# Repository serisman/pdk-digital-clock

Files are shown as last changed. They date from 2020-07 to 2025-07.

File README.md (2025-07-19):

# pdk-digital-clock
A 4-digit 7-segment digital clock, based on the inexpensive 8-bit Padauk microcontrollers

This project uses the [SLR0394DRC5BD](https://lcsc.com/product-detail/Led-Segment-Display_SUNLIGHT-SLR0394DRA5BD_C225902.html) 4-digit 7-segment common cathode 'time' display,
which sits over the top of a 74HC595 and (2) 4x resistor packs.
The 74HC595 is used to enable each of the four 7-segment digits, one at a time, using two output pins per digit for extra current sink capabilities.
The segments themselves are driven directly by the Port B outputs of the Padauk microcontroller.
Each of the four 7-segment digits is enabled and updated, one at a time, several 10's of times a second.

### Default Firmware (Push Button)
- Link: [Firmware](firmware/)

A single push button is used to set the time, with the following 'user interface':
- A short press will temporarily show the current 'seconds'.
- A medium-press will switch to time config mode.  While in config mode:
  - A short press will increment the currently selected time value, with rollover.
  - A medium-press will switch to the next time value, or exit config mode if on the last time value.
  - A long-press will exit config mode. 

### Alternate Firmware (Serial)
- Link: [Firmware-Serial](firmware-serial/)

This alternate firmware allows the time to be set by a serial command instead of requiring button presses.
This makes it easier to keep time updated and synced after it naturally drifts due to crystal accuracy and temperature fluctuations.

To set/update time, connect a Serial UART's TX pin (TTL level) to pin PA5 (PIN_RX):
- Send the following 5 bytes @9600 baud (1 start bit, 8 data bits, 1 stop bit, no parity):
    - `start byte`: 0x00
    - `hours byte`: using bcd notation, bit[7] is am_pm indicator, bits[5:4] is hours_10, bits[3:0] is hours_01
    - `minutes byte`: using bcd notation, bits[6:4] is minutes_10, bits[3:0] is minutes_01
    - `seconds byte`: using bcd notation, bits[6:4] is seconds_10, bits[3:0] is seconds_01
    - `checksum byte`: the sum of all preceding data bytes.

### Power Consumption

This digital clock is powered via micro USB cable, although it should work at much lower voltages as well.
It isn't really suitable for long-term battery operation, as the LED based 7-segment display consumes enough energy that the battery wouldn't last very long.

#### Power consumption (displaying 12:00):
- @ 5.0V = ~19mA
- @ 4.5V = ~16mA
- @ 4.0V = ~13mA
- @ 3.5V = ~10mA
- @ 3.0V = ~7mA
- @ 2.5V = ~4mA
- @ 2.0V = ~1mA

### PCB
- Design Files: [KiCad](pcb-s16/)
- Shared: [OSHPARK](https://oshpark.com/shared_projects/jvGgF1gC)

### Schematic
(for 16-pin PFS154, PFS173, PMS152, or PMS154C)
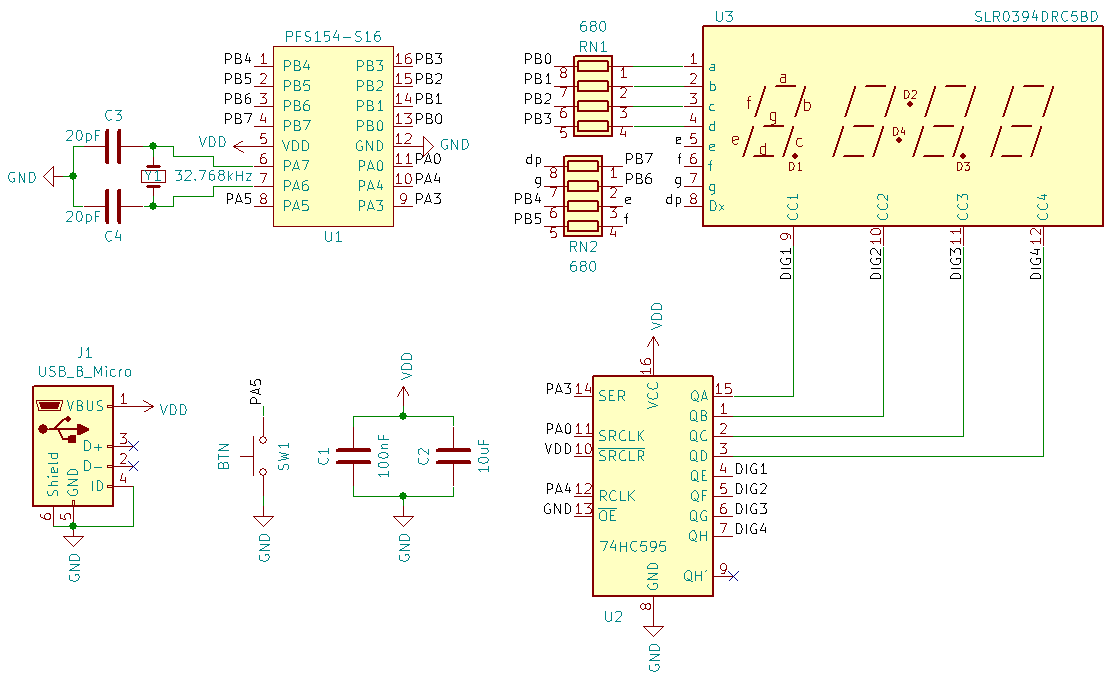
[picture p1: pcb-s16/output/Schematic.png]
Schematic
> 

### Compatibility
This project is currently intended to be run (without modifications) on the PFS154, PFS173, PMS152, and PMS154C Padauk microcontrollers,
but it should be able to be modified to run on other 16-pin Padauk microcontrollers that are supported by SDCC and the Easy PDK Programmer.

### Bill of Materials
| Ref | Part # | Description | Footprint | Purchase Link | Price | Minimum Purchase |
| --- | --- | --- | --- | --- | --- | --- |
| PCB | - | - | - | [OSHPARK](https://oshpark.com/shared_projects/jvGgF1gC) | $1.033 each | $3.10 for 3 |
| U3 | SLR0394DRA5BD | 4-digit time-mode 7-segment display | - | [LCSC C225902](https://lcsc.com/product-detail/Led-Segment-Display_SUNLIGHT-SLR0394DRA5BD_C225902.html) | $0.501 each | $0.501 for 1|  
| U1 | PMS152-S16 | 8-bit Padauk microcontroller | SOP-16 | [LCSC C317590](https://lcsc.com/product-detail/Others_PADAUK-Tech-PMS152-S16_C317590.html) | $0.077 each | $0.39 for 5 |
| U2 | 74HC595D | Serial shift register | SOP-16 | [LCSC C93838](https://lcsc.com/product-detail/LED-Drivers_Shenzhen-Sunmoon-Micro-SM74HC595D_C93838.html) | $0.046 each | $0.46 for 10 |
| Y1 | - | 32.767KHz radial cylinder crystal | 2x6mm | [LCSC C2236](https://lcsc.com/product-detail/Radial-Cylinder-Crystals_Yangxing-Tech-X206032768KGB2SC_C2236.html) | $0.045 each | $0.45 for 10 |
| J1 | - | Micro USB connector | - | [LCSC C393940](https://lcsc.com/product-detail/USB-Connectors_SHOU-HAN-MICRO5-9mmusb_C393940.html) | $0.026 each | $0.52 for 20 | 
| SW1 | TS24CA | SPST side-actuated button tactile switch | - | [LCSC C393942](https://lcsc.com/product-detail/Tactile-Switches_SHOU-HAN-TS24CA_C393942.html) | $0.025 each | $0.50 for 20 |
| C2 | - | 10uF capacitor | 0805 | [LCSC C92786](https://lcsc.com/product-detail/Multilayer-Ceramic-Capacitors-MLCC-SMD-SMT_Taiyo-Yuden_JMK212BJ106KD-T_Taiyo-Yuden-JMK212BJ106KD-T_C92786.html) | $0.015 each | $0.73 for 50 |
| C3,C4 | - | 20pF capacitor | 0805 | [LCSC C309037](https://lcsc.com/product-detail/Multilayer-Ceramic-Capacitors-MLCC-SMD-SMT_CCTC-TCC0805C0G200J500BT_C309037.html) | $0.007 each | $0.36 for 50 |
| RN1,RN2 | - | 4x 680 ohm resistor network | 0603_x4 | [LCSC C102679](https://lcsc.com/product-detail/Resistor-Networks-Arrays_RALEC-RTA03-4D681JTP_C102679.html) | $0.007 each | $0.35 for 50 |
| C1 | - | 100nF capacitor | 0805 | [LCSC C235732](https://lcsc.com/product-detail/Multilayer-Ceramic-Capacitors-MLCC-SMD-SMT_PSA-Prosperity-Dielectrics-FN21X104K500PXG_C235732.html) | $0.006 each | $0.30 for 50 |

Total: ~$1.80 each (+/- depending on quantity)

### Images
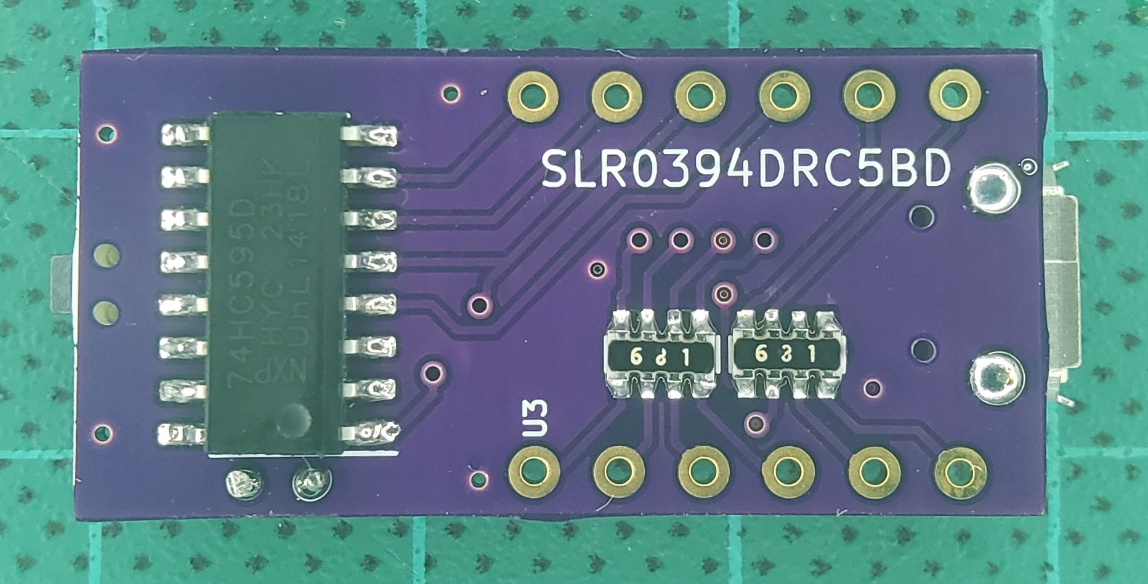
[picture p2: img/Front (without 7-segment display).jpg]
Front (without 7-segment display)

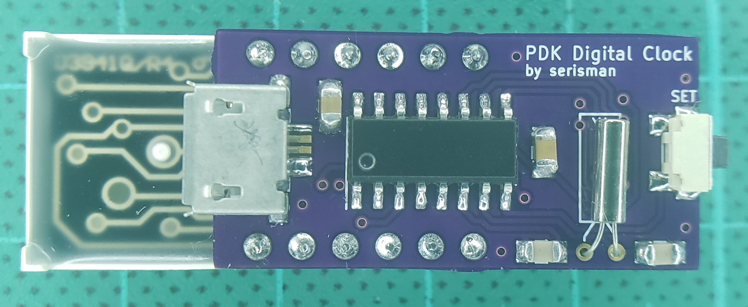
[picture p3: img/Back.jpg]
Back

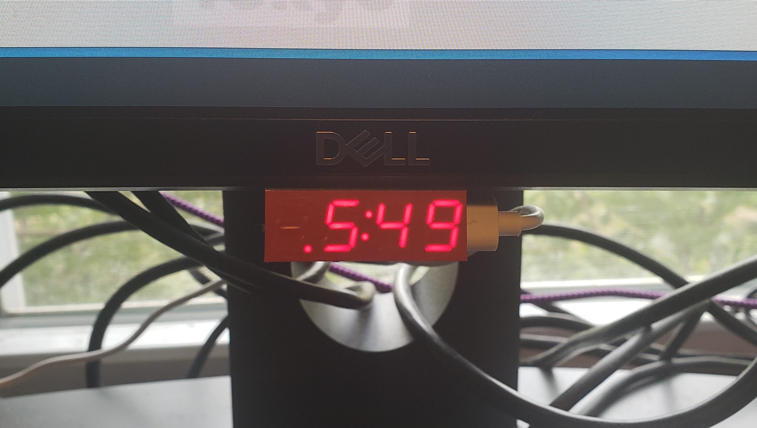
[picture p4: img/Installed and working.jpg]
Installed and working!


### Copyright and License:
- Copyright (C) 2020 - serisman (github@serisman.com)
- License: [GPL v3 (or later)](LICENSE)

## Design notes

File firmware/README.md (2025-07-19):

# firmware ([pdk-digital-clock](https://github.com/serisman/pdk-digital-clock/))

A single push button is used to set the time, with the following 'user interface':
- A short press will temporarily show the current 'seconds'.
- A medium-press will switch to time config mode.  While in config mode:
    - A short press will increment the currently selected time value, with rollover.
    - A medium-press will switch to the next time value, or exit config mode if on the last time value.
    - A long-press will exit config mode.

### Toolchain:
- The open-source [Small Device C Compiler (SDCC)](http://sdcc.sourceforge.net/)
  - Requires version 4.4.0+
- The open-source [Easy PDK Programmer](https://github.com/free-pdk/easy-pdk-programmer-software)
  - Requires version 1.3 or newer
- The open-source [pdk-includes](https://github.com/free-pdk/pdk-includes) repository
  - Integrated via local copy into the pdk/ directory
- The open-source [easy-pdk-includes](https://github.com/free-pdk/easy-pdk-includes) repository
  - Integrated via local copy into the easy-pdk/ directory
- Also requires 'make' and other common build tools

### Build Commands:
```
make clean
make build
make size (also calls build)
make program (also calls size which calls build)
make run
```
> Note: These commands can be chained as well.  i.e. `make clean program run`

### Customization:
Edit the variables at the top of the Makefile to:
- **DEVICE**: Use a different Padauk MCU (defaults to PFS154)
- **F_CPU**: Use a different frequency for the system clock (defaults to 524.288 kHz, i.e. IHRC/32)
  > Note: Valid choices are: 524288 to use the IHRC, or 65536 to use the ILRC.  These values make it easier for timekeeping (although true accuracy only comes from using an external crystal).
- **TARGET_VDD_MV**: Use a different voltage while calibrating the internal oscillator (IHRC or ILRC) (defaults to 4000mV)
- **TARGET_VDD**: Use a different voltage while the IC is operating (defaults to 4.0V)
- **DEBUG**: If set to 1, the 16-bit timer will use the less accurate internal oscillator instead of requiring an external crystal (defaults to 0)

> Note: All of these variables can be changed on the commandline as well.  i.e. `make DEVICE=PFS173 clean program run` 

### Compatibility
This project is currently intended to be run (without modifications) on the PFS154, PFS173, PMS152, and PMS154C Padauk microcontrollers,
but it should be able to be modified to run on other 16-pin Padauk microcontrollers that are supported by SDCC and the Easy PDK Programmer.
Less common devices may require additional device specific include files (pdk/device/*.h) to be supplied.

### Build Stats
- Code Size: ~463 words
- RAM usage: 22 bytes + stack

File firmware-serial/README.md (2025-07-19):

# firmware-serial ([pdk-digital-clock](https://github.com/serisman/pdk-digital-clock/))

This alternate firmware allows the time to be set by a serial command instead of requiring button presses.
This makes it easier to keep time updated and synced after it naturally drifts due to crystal accuracy and temperature fluctuations.

To set/update time, connect a Serial UART's TX pin (TTL level) to pin PA5 (PIN_RX):
- Send the following 5 bytes @9600 baud (1 start bit, 8 data bits, 1 stop bit, no parity):
  - `start byte`: 0x00
  - `hours byte`: using bcd notation, bit[7] is am_pm indicator, bits[5:4] is hours_10, bits[3:0] is hours_01
  - `minutes byte`: using bcd notation, bits[6:4] is minutes_10, bits[3:0] is minutes_01
  - `seconds byte`: using bcd notation, bits[6:4] is seconds_10, bits[3:0] is seconds_01
  - `checksum byte`: the sum of all preceding data bytes.

### Toolchain:
- The open-source [Small Device C Compiler (SDCC)](http://sdcc.sourceforge.net/)
  - Requires version 4.4.0+
- The open-source [Easy PDK Programmer](https://github.com/free-pdk/easy-pdk-programmer-software)
  - Requires version 1.3 or newer
- The open-source [pdk-includes](https://github.com/free-pdk/pdk-includes) repository
  - Integrated via local copy into the pdk/ directory
- The open-source [easy-pdk-includes](https://github.com/free-pdk/easy-pdk-includes) repository
  - Integrated via local copy into the easy-pdk/ directory
- Also requires 'make' and other common build tools

### Build Commands:
```
make clean
make build
make size (also calls build)
make program (also calls size which calls build)
make run
```
> Note: These commands can be chained as well.  i.e. `make clean program run`

### Customization:
Edit the variables at the top of the Makefile to:
- **DEVICE**: Use a different Padauk MCU (defaults to PFS154)
- **F_CPU**: Use a different frequency for the system clock (defaults to 524.288 kHz, i.e. IHRC/32)
  > Note: Only valid choice is: 524288 to use the IHRC.  This value make it easier for timekeeping (although true accuracy only comes from using an external crystal).
          Changing this would also require changes to the UART receive code which has very precise timing requirements.
- **TARGET_VDD_MV**: Use a different voltage while calibrating the internal oscillator (IHRC or ILRC) (defaults to 3300mV)
- **TARGET_VDD**: Use a different voltage while the IC is operating (defaults to 3.3V)
- **DEBUG**: If set to 1, the 16-bit timer will use the less accurate internal oscillator instead of requiring an external crystal (defaults to 0)

> Note: All of these variables can be changed on the commandline as well.  i.e. `make DEVICE=PFS173 clean program run` 

### Compatibility
This project is currently intended to be run (without modifications) on the PFS154, PFS173, PMS152, and PMS154C Padauk microcontrollers,
but it should be able to be modified to run on other 16-pin Padauk microcontrollers that are supported by SDCC and the Easy PDK Programmer.
Less common devices may require additional device specific include files (pdk/device/*.h) to be supplied.

### Build Stats
- Code Size: ~365 words
- RAM usage: 28 bytes + stack

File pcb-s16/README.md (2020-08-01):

# pcb-s16 ([pdk-digital-clock](https://github.com/serisman/pdk-digital-clock/))

### Schematic
(for 16-pin PFS154, PFS173, PMS152, or PMS154C)
> Schematic

### PCB

This PCB design was created with KiCad, and has been [shared on OSHPARK](https://oshpark.com/shared_projects/jvGgF1gC).
There are also gerber files available in the [output/gerber/](output/gerber/) directory.

This uses the [SLR0394DRC5BD](https://lcsc.com/product-detail/Led-Segment-Display_SUNLIGHT-SLR0394DRA5BD_C225902.html) 4-digit 7-segment common cathode 'time' display,
which sits over the top of the 74HC595 and the (2) 4x resistor packs.
The 74HC595 is used to drive the (4) 7-segment digits, (2) outputs per digit for extra current sink capabilities.
The segments themselves are driven directly by the Port B outputs of the Padauk microcontroller.

A single push button is used to set the time, with the following 'user interface':
- A short press will temporarily show the current 'seconds'.
- A medium-press will switch to time config mode.  While in config mode:
  - A short press will increment the currently selected time value, with rollover.
  - A medium-press will switch to the next time value, or exit config mode if on the last time value.
  - A long-press will exit config mode. 

This digital clock is powered via micro USB cable, although it should work at much lower voltages as well.
It isn't really suitable for long-term battery operation, as the LED based 7-segment display consumes enough energy that it wouldn't last very long.

### Bill of Materials
| Ref | Part # | Description | Footprint | Purchase Link | Price | Minimum Purchase |
| --- | --- | --- | --- | --- | --- | --- |
| PCB | - | - | - | [OSHPARK](https://oshpark.com/shared_projects/jvGgF1gC) | $1.033 each | $3.10 for 3 |
| U3 | SLR0394DRA5BD | 4-digit time-mode 7-segment display | - | [LCSC C225902](https://lcsc.com/product-detail/Led-Segment-Display_SUNLIGHT-SLR0394DRA5BD_C225902.html) | $0.501 each | $0.501 for 1|  
| U1 | PMS152-S16 | 8-bit Padauk microcontroller | SOP-16 | [LCSC C317590](https://lcsc.com/product-detail/Others_PADAUK-Tech-PMS152-S16_C317590.html) | $0.077 each | $0.39 for 5 |
| U2 | 74HC595D | Serial shift register | SOP-16 | [LCSC C93838](https://lcsc.com/product-detail/LED-Drivers_Shenzhen-Sunmoon-Micro-SM74HC595D_C93838.html) | $0.046 each | $0.46 for 10 |
| Y1 | - | 32.767KHz radial cylinder crystal | 2x6mm | [LCSC C2236](https://lcsc.com/product-detail/Radial-Cylinder-Crystals_Yangxing-Tech-X206032768KGB2SC_C2236.html) | $0.045 each | $0.45 for 10 |
| J1 | - | Micro USB connector | - | [LCSC C393940](https://lcsc.com/product-detail/USB-Connectors_SHOU-HAN-MICRO5-9mmusb_C393940.html) | $0.026 each | $0.52 for 20 | 
| SW1 | TS24CA | SPST side-actuated button tactile switch | - | [LCSC C393942](https://lcsc.com/product-detail/Tactile-Switches_SHOU-HAN-TS24CA_C393942.html) | $0.025 each | $0.50 for 20 |
| C2 | - | 10uF capacitor | 0805 | [LCSC C92786](https://lcsc.com/product-detail/Multilayer-Ceramic-Capacitors-MLCC-SMD-SMT_Taiyo-Yuden_JMK212BJ106KD-T_Taiyo-Yuden-JMK212BJ106KD-T_C92786.html) | $0.015 each | $0.73 for 50 |
| C3,C4 | - | 20pF capacitor | 0805 | [LCSC C309037](https://lcsc.com/product-detail/Multilayer-Ceramic-Capacitors-MLCC-SMD-SMT_CCTC-TCC0805C0G200J500BT_C309037.html) | $0.007 each | $0.36 for 50 |
| RN1,RN2 | - | 4x 680 ohm resistor network | 0603_x4 | [LCSC C102679](https://lcsc.com/product-detail/Resistor-Networks-Arrays_RALEC-RTA03-4D681JTP_C102679.html) | $0.007 each | $0.35 for 50 |
| C1 | - | 100nF capacitor | 0805 | [LCSC C235732](https://lcsc.com/product-detail/Multilayer-Ceramic-Capacitors-MLCC-SMD-SMT_PSA-Prosperity-Dielectrics-FN21X104K500PXG_C235732.html) | $0.006 each | $0.30 for 50 |

Total: ~$1.80 each (+/- depending on quantity)

### PCB Renders

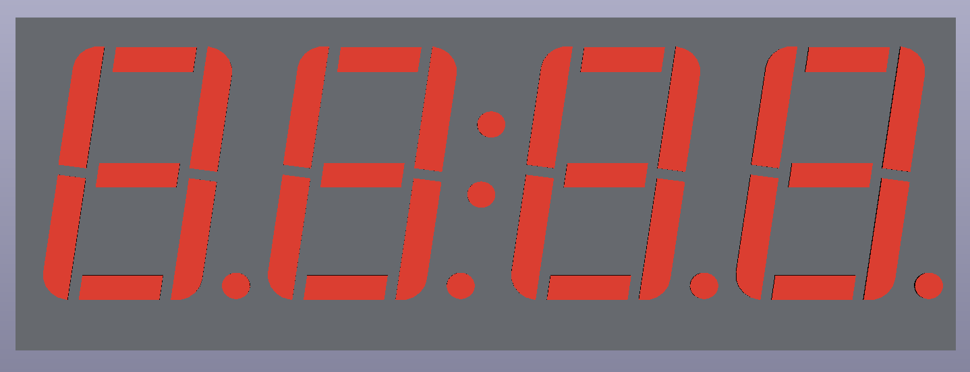
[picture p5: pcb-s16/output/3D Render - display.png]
3D Render - display

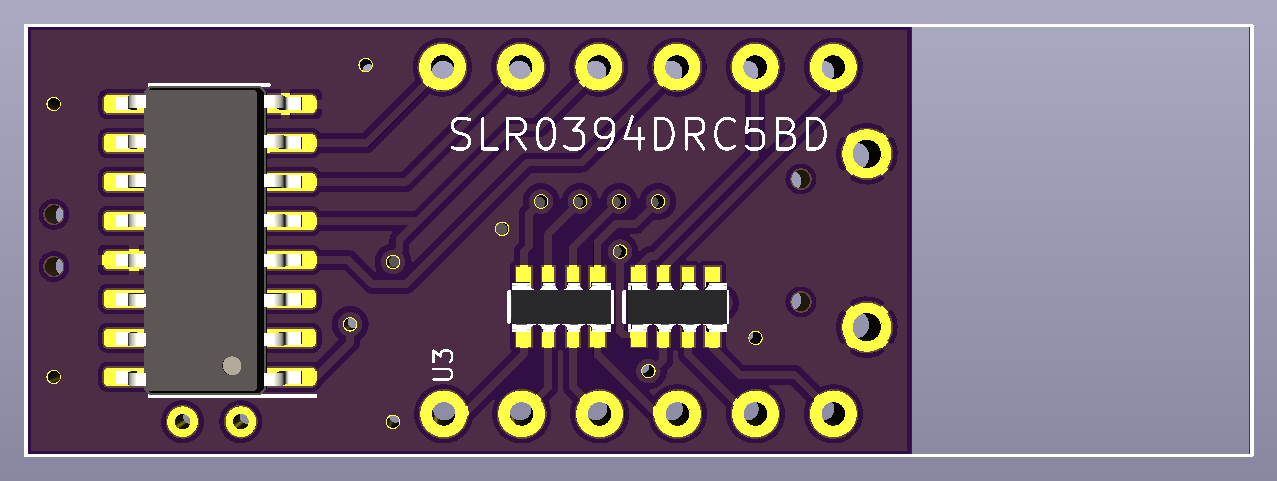
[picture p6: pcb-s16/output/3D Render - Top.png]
3D Render - Top

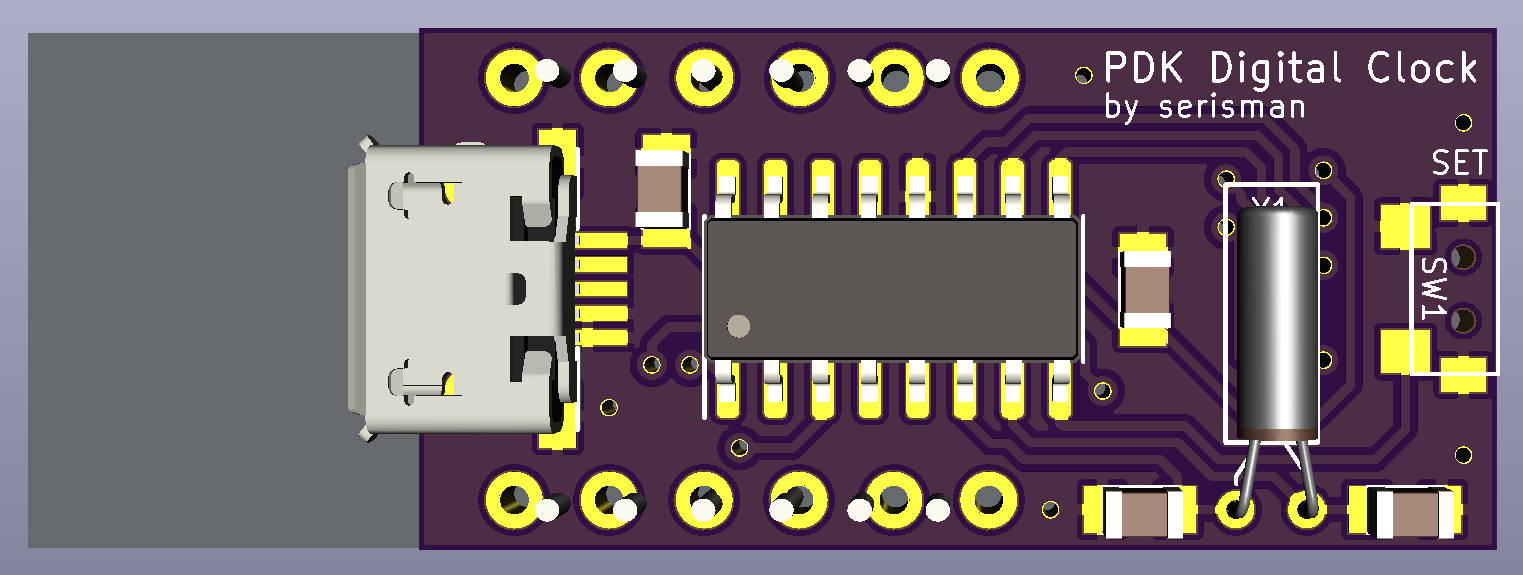
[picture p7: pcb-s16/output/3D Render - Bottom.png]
3D Render - Bottom

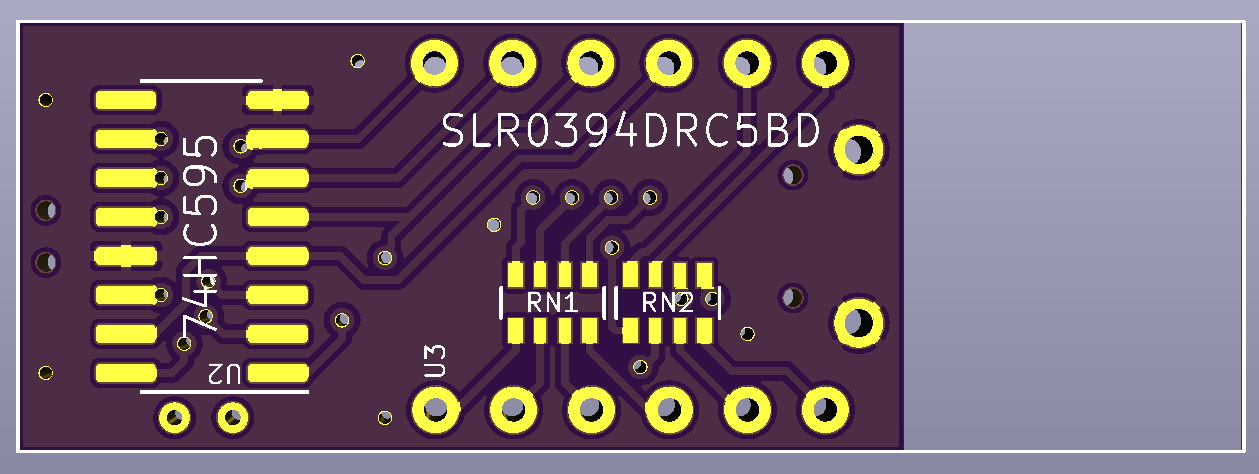
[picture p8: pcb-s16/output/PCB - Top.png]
PCB Top

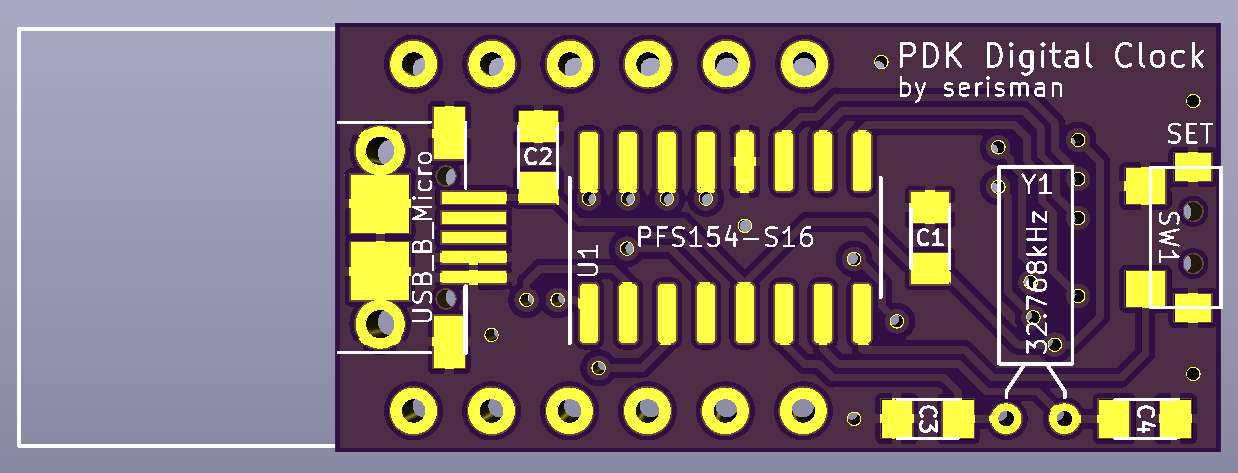
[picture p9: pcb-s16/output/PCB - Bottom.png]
PCB Bottom


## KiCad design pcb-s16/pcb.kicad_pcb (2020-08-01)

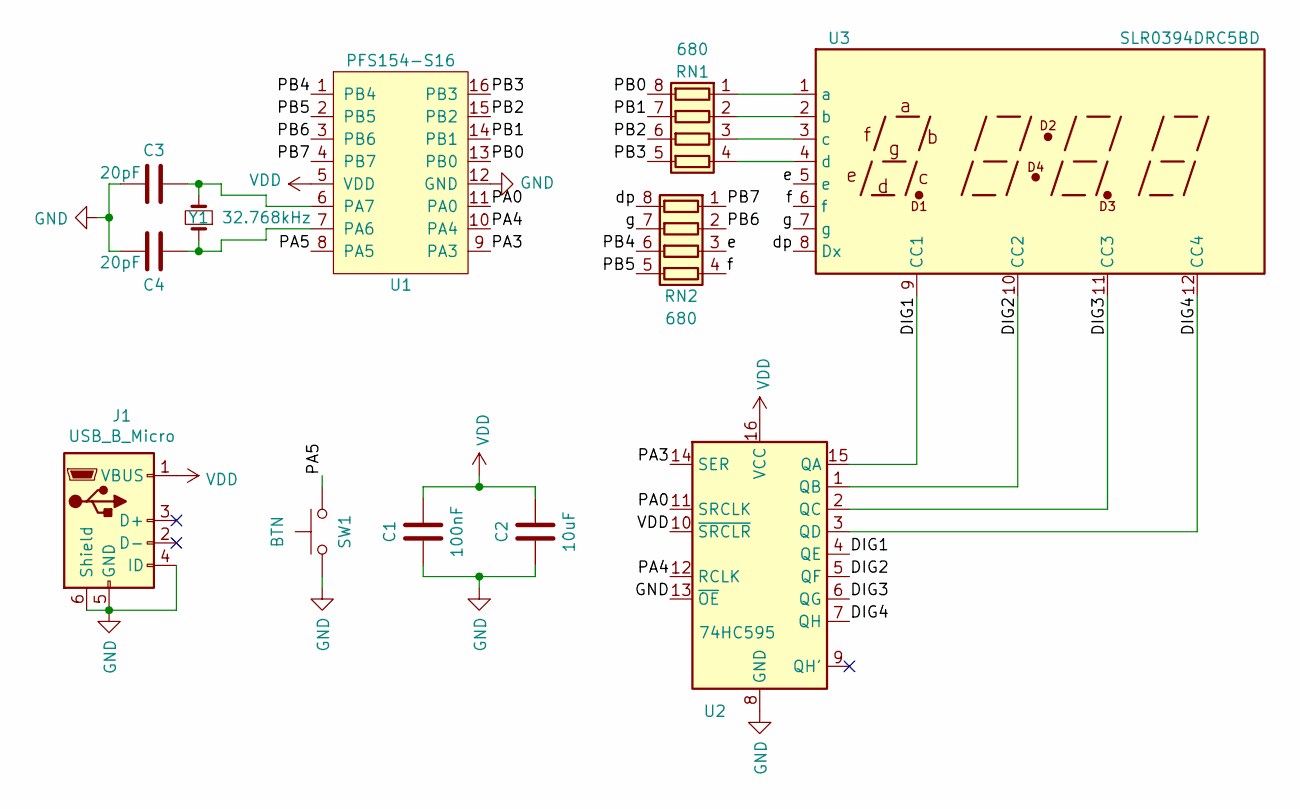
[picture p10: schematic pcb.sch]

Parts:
C1: 100nF; C_0805
C2: 10uF; C_0805
C3, C4: 20pF; C_0805
J1: USB_B_Micro; USB_Micro_B_Male
RN1, RN2: 680; R_Array_Convex_4x0603
SW1: BTN; SMD-SW_Push_3.5x4.55_Side
U1: PFS154-S16; SOIC-16_3.9x9.9mm_P1.27mm
U2: 74HC595; SOIC-16_3.9x9.9mm_P1.27mm
U3: SLR0394DRC5BD; SLR039DRC5BD
Y1: 32.768kHz; Crystal_C26-LF_D2.1mm_L6.5mm_Horizontal

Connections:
/DIG1: U2.4 (QE), U2.15 (QA), U3.9 (CC1)
/DIG2: U2.1 (QB), U2.5 (QF), U3.10 (CC2)
/DIG3: U2.2 (QC), U2.6 (QG), U3.11 (CC3)
/DIG4: U2.3 (QD), U2.7 (QH), U3.12 (CC4)
/PA0: U1.11 (PA0), U2.11 (SRCLK)
/PA3: U1.9 (PA3), U2.14 (SER)
/PA4: U1.10 (PA4), U2.12 (RCLK)
/PA5: SW1.2, U1.8 (PA5)
/PB0: RN1.8 (R1.2), U1.13 (PB0)
/PB1: RN1.7 (R2.2), U1.14 (PB1)
/PB2: RN1.6 (R3.2), U1.15 (PB2)
/PB3: RN1.5 (R4.2), U1.16 (PB3)
/PB4: RN2.6 (R3.2), U1.1 (PB4)
/PB5: RN2.5 (R4.2), U1.2 (PB5)
/PB6: RN2.2 (R2.1), U1.3 (PB6)
/PB7: RN2.1 (R1.1), U1.4 (PB7)
/dp: RN2.8 (R1.2), U3.8 (Dx)
/e: RN2.3 (R3.1), U3.5 (e)
/f: RN2.4 (R4.1), U3.6 (f)
/g: RN2.7 (R2.2), U3.7 (g)
GND: C1.2, C2.2, C3.1, C4.1, J1.4 (ID), J1.5 (GND), J1.6 (Shield), SW1.1, SW1.SH, U1.12 (GND), U2.8 (GND), U2.13 (~OE)
unnamed: C3.2, U1.6 (PA7), Y1.2
unnamed: C4.2, U1.7 (PA6), Y1.1
unnamed: RN1.1 (R1.1), U3.1 (a)
unnamed: RN1.2 (R2.1), U3.2 (b)
unnamed: RN1.3 (R3.1), U3.3 (c)
unnamed: RN1.4 (R4.1), U3.4 (d)
VDD: C1.1, C2.1, J1.1 (VBUS), U1.5 (VDD), U2.10 (~SRCLR), U2.16 (VCC)

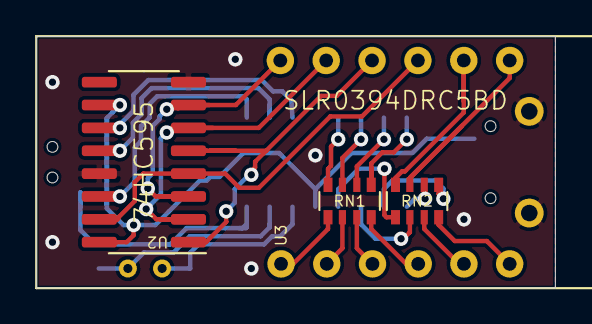
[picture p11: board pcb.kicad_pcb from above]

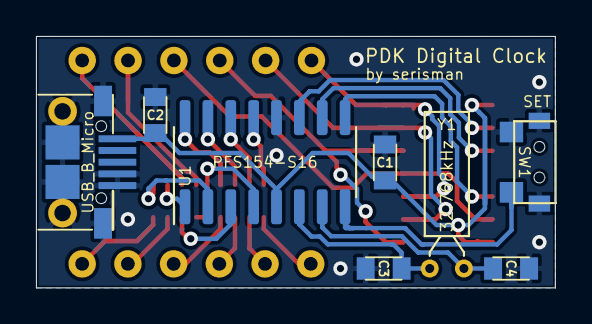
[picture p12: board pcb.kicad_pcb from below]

Board: 2 copper layers, 28.8 x 14.0 mm, 12 parts (8 on the bottom side), 28 nets.

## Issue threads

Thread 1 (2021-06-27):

Issue with pfs173 reset pin as a PRSTB function

Vanbatai123, 2021-06-27:
Hi sir!
I have an issue that how to configure pin A5 as a PRSTB reset pin, i have read datasheet and try it like this but did not work.

uint8_t _sdcc_external_startup(void)
{
	PAC &= ~(1<<5);
	CLKMD |= (1<<0);
	EASY_PDK_INIT_SYSCLOCK_8MHZ();		  //use 8MHz sysclock
	EASY_PDK_CALIBRATE_IHRC(F_CPU, 5000); //tune SYSCLK to 8MHz @ 4.000V
	return 0;							  //perform normal initialization
}
thank in advance.

Closed 2022-07-05.

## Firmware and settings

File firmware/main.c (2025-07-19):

/*
  main.c: Main program code for the PDK digital clock project.

  Copyright (C) 2020  serisman  <github@serisman.com>

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
  You should have received a copy of the GNU General Public License
  along with this program.  If not, see <http://www.gnu.org/licenses/>.
*/

#include <pdk/device.h>
#include <easy-pdk/calibrate.h>
#include "util.h"

#define PORT_SEGMENTS   PB
#define PIN_SR_DATA     PA,3
#define PIN_SR_CLOCK    PA,0
#define PIN_SR_LATCH    PA,4

#define PIN_BTN         PA,5

volatile uint8_t quarter_seconds;

// Initialize clock to 12:00:00 AM
uint8_t hours_10=1, hours_01=2, minutes_10, minutes_01, seconds_10, seconds_01, am_pm;

// Initialize display to --:--
uint8_t digit1=0b01000000, digit2=0b01000000, digit3=0b01000000, digit4=0b01000000;
uint8_t current_digit_mask = 0b10001000;

uint8_t _tmp, prev_quarter_seconds, btn_ctr, display_mode, config_mode, config_ctr;

// void display_next_digit()
//
//  Rotates to and outputs a single digit 'register' for a 4-digit 7-segment display.
//  NOTE: This should be called multiple 100's of times a second to light up all the digits for 'persistence of vision'.
//    This method has been written in assembly to make it as small and fast as possible.
//  This uses a 74HC595 as a digit 'driver' which provides two benefits:
//   1. Enables 4 (or more) outputs (digits) from 3 IO pins.
//   2. Enables a higher current sink for each digit than IO pins would otherwise allow.
//  We double up the 74HC595 output pins (i.e. 2 per digit) for extra current sink capability.
//
//  Assumes (#define'd above):
//   Segments[a-g,dp] are mapped to PB[0-7]
//   74HC595 (14) DS - DATA is on PA3
//   74HC595 (11) SH_CP - CLOCK is on PA0
//   74HC595 (12) ST_CP - LATCH is on PA4
void display_next_digit(void) {
__asm
	;// Rotate to next digit
  set0.io  f, c
  t0sn  _current_digit_mask, #7
    set1.io  f, c
  slc   _current_digit_mask

	;// Shift out /EN for all digits to 74HC595
	mov   a, _current_digit_mask
	mov   __tmp, a
	mov   a, #8
00001$:
	set1.io  _REG(PIN_SR_DATA), #_BIT(PIN_SR_DATA)
	t0sn  __tmp, #7
		set0.io  _REG(PIN_SR_DATA), #_BIT(PIN_SR_DATA)
	set1.io  _REG(PIN_SR_CLOCK), #_BIT(PIN_SR_CLOCK)
	set0.io  _REG(PIN_SR_CLOCK), #_BIT(PIN_SR_CLOCK)
	sl    __tmp
	dzsn  a
		goto  00001$
	set1.io  _REG(PIN_SR_DATA), #_BIT(PIN_SR_DATA)

	;// Get the current digit's segments
	t0sn  _current_digit_mask, #0
		mov   a, _digit1
	t0sn  _current_digit_mask, #1
		mov   a, _digit2
	t0sn  _current_digit_mask, #2
		mov   a, _digit3
	t0sn  _current_digit_mask, #3
		mov   a, _digit4
	mov   __tmp, a

	;// Disable the previous digit's segments
	disgint
	mov   a, #0b00000000
	mov.io   _REG(PORT_SEGMENTS), a

	;// Latch 74HC595 - Enables the digit that was set low
	set1.io  _REG(PIN_SR_LATCH), #_BIT(PIN_SR_LATCH)

	;// Enable the current digit's segments
	mov   a, __tmp
	mov.io   _REG(PORT_SEGMENTS), a
	engint

	set0.io  _REG(PIN_SR_LATCH), #_BIT(PIN_SR_LATCH)

__endasm;
}

// uint8_t bcd_to_7segment(uint8_t bcd)
//
//  Given a number 0 through 9, will return a 7 segment digit mask representation of said number
//  Assumes bits 0-6 maps to the top segment, then the other segments in a clockwise circle, and finally the middle segment,
//    with bit 7 being the 'dot'
uint8_t bcd_to_7segment(uint8_t bcd) __naked {
//	if (bcd > 9) return 0b00000000;
//	switch (bcd) {
//		case 0: return 0b00111111;
//		case 1: return 0b00000110;
//		case 2: return 0b01011011;
//		case 3: return 0b01001111;
//		case 4: return 0b01100110;
//		case 5: return 0b01101101;
//		case 6: return 0b01111101;
//		case 7: return 0b00000111;
//		case 8: return 0b01111111;
//		case 9: return 0b01100111;
//	}
	bcd; // Ignore unreferenced function argument warning
__asm
	;// Make sure bcd is <= 9 (otherwise unexpected results would occur!)
	mov	a, #9
	sub	a, _bcd_to_7segment_PARM_1
	t0sn.io	f, c
		ret	#0b00000000
	;// Lookup and return 7-segment representation
	mov   a, _bcd_to_7segment_PARM_1
	add   a, #1
	pcadd a
	ret   #0b00111111     ;// 0
	ret   #0b00000110     ;// 1
	ret   #0b01011011     ;// 2
	ret   #0b01001111     ;// 3
	ret   #0b01100110     ;// 4
	ret   #0b01101101     ;// 5
	ret   #0b01111101     ;// 6
	ret   #0b00000111     ;// 7
	ret   #0b01111111     ;// 8
	ret   #0b01101111     ;// 9
__endasm;
}

// Increment the clock's time values with cascading roll-overs
// NOTE: This needs to be called EXACTLY once a second!
void update_clock(void) {
  if (++seconds_01 == 10) {
    seconds_01=0;
    if (++seconds_10 == 6) {
      seconds_10=0;
      if (++minutes_01 == 10) {
        minutes_01=0;
        if (++minutes_10 == 6) {
          minutes_10=0;
          hours_01++;
          if (hours_10 == 0 && hours_01 == 10) {
            hours_01=0;
            hours_10++;
          } else if (hours_10 == 1 && hours_01 == 3) {
            hours_01=1;
            hours_10=0;
          } else if (hours_10 == 1 && hours_01 == 2) {
            am_pm = 1-am_pm;
          }
        }
      }
    }
  }
}

// Write the current time (seconds or hours:minutes) to the 4x 7-segment digit 'registers'
void update_time_display(void) {
	if (display_mode) {
    // Seconds
		digit1 = 0b01101101;    // 'S'
		digit2 = 0;
		digit3 = bcd_to_7segment(seconds_10);
		digit4 = bcd_to_7segment(seconds_01);

		if (display_mode++ == 4) display_mode = 0;  // Revert to HH:MM display after a second or so
	} else {
		// Hours
		digit1 = 0b00000000; // Don't display leading 0 for hours
		if (hours_10)
			digit1 = bcd_to_7segment(hours_10);
		digit2 = bcd_to_7segment(hours_01);

		// Minutes
		digit3 = bcd_to_7segment(minutes_10);
		digit4 = bcd_to_7segment(minutes_01);

		// AM/PM indicator
		if (am_pm)
			setBit(digit1,7);
	}

	// Blink the half-second indicator
	if (quarter_seconds & 0b00000010) {
		setBit(digit2,7);
		setBit(digit4,7);
	}
}

// Write the current config variable to the 4x 7-segment digit 'registers'
void update_config_display(void) {
	digit1=digit2=digit3=digit4=0;

	if (/*config_mode == 1 || config_mode == 2*/ config_mode < 3) {
		// Seconds
		digit1 = 0b01101101;    // 'S'
		digit3 = bcd_to_7segment(seconds_10);
		digit4 = bcd_to_7segment(seconds_01);
  } else if (/*config_mode > 2 &&*/ config_mode < 7) {
    // Hours:Minutes
		digit1 = bcd_to_7segment(hours_10);
    digit2 = bcd_to_7segment(hours_01);
    digit3 = bcd_to_7segment(minutes_10);
    digit4 = bcd_to_7segment(minutes_01);
   } else /*if (config_mode == 7)*/ {
		if (am_pm) {
			digit1 = 0b01110011;  // 'P'
		} else {
			digit1 = 0b01110111;  // 'A'
		}
	}

  // Blink the current config variable digit
	if (quarter_seconds & 0b00000001) {
		switch (config_mode) {
			case 1:
			case 3: digit4 = 0; break;
			case 2:
			case 4: digit3 = 0; break;
			case 5: digit2 = 0; break;
			case 6:
			case 7: digit1 = 0; break;
		}
	} else {
	  // Blink the seconds indictor as a config indicator
  	setBit(digit2,7);
	  setBit(digit4,7);
	}
}

// Write the appropriate 'screen' to the 4x 7-segment digit 'registers'
void update_display(void) {
  if (!config_mode) {
    update_time_display();
  } else {
    update_config_display();
  }
}

// Increment the current config variable with reset on rollover
void increment_config_value(void) {
	switch (config_mode) {
		case 1: if (++seconds_01 == 10) seconds_01 = 0;	break;
		case 2:	if (++seconds_10 == 6) seconds_10 = 0;	break;
		case 3:	if (++minutes_01 == 10) minutes_01 = 0;	break;
		case 4:	if (++minutes_10 == 6) minutes_10 = 0;	break;
		case 5:	if (++hours_01 == 10) hours_01 = 0;	break;
		case 6:	hours_10 = 1-hours_10;	break;
		case 7:	am_pm = 1-am_pm;	break;
	}
}

// Check the button's state and process button up/down events
void process_btn(void) {
	if (isPinLow(PIN_BTN)) {
		if (!btn_ctr) {               // On button down
			btn_ctr = 1;
			display_mode = 1;           // Briefly show Seconds
      update_display();
		} else if (btn_ctr == 5) {    // Long press (don't wait for button up)
			btn_ctr++;
			display_mode = 0;
      config_mode++;              // Enter config / Move to next config setting
      config_ctr = 1;
      if (config_mode == 8) {
        config_mode = 0;          // Exit config
      }
      update_display();
    } else if (btn_ctr == 14) {   // Really long press (don't wait for button up)
      btn_ctr++;
      config_mode = 0;            // Exit config
      update_display();
    }
	} else if (btn_ctr) {           // On button up
		if (btn_ctr < 5) {            // Short press (wait for button up)
			if (config_mode) {
			  config_ctr = 1;
				increment_config_value(); // Increment config setting
			}
			update_display();
		}
		btn_ctr = 0;
	}
}

// Process things that we want done every 1/4 seconds
void every_quarter_second(void) {
	if ((quarter_seconds & 0b00000011) == 0b00000011) {
    update_clock();
  }
  if (btn_ctr && btn_ctr != 255) {
 		btn_ctr++;
	}
	if (config_mode && config_ctr++ == 40) {
    config_mode = 0;            // Exit config (timeout)
	}
  update_display();
}

// Main program
void main(void) {
  // Make sure PA7/PA6 is Disabled for External Crystal (recommended for all ICs)
  // Make sure PA5 is Enabled as input for Button (needed by PMS152/PFS173)
  PADIER = 0b00100000;

	// Set appropriate pins as outputs (all pins are input by default)
	PAC = 0b00011001;           // Set PA[0,3,4] to output (74HC595 for digits)
	PBC = 0xFF;                 // Set Port B[0-7] to output (segments)
	setPinPullup(PIN_BTN);

	// Enable T16 timer to generate an interrupt every 1/4 seconds
#if (DEBUG == 1)
	#if (F_CPU == 65536)
		T16M = 0b11010001;        // Use ILRC clock source (65.536 kHz), /16, Interrupt on (rising) Bit 9
	#elif (F_CPU == 524288)
		T16M = 0b00111010;        // Use System (IHRC) clock source (524.288 kHz), /64, Interrupt on (rising) Bit 10
	#endif
#else
	EOSCR = 0b10100000;         // Enable External Oscillator (32kHz crystal)
	T16M = 0b10110000;          // Use EOSC clock source (32.768 kHz), /16, Interrupt on (rising) Bit 8
#endif
	T16C = 0;
	INTEN = INTEN_T16;

	// Enable interrupts
	INTRQ = 0;
	__engint();

  // Main processing loop
	while(1) {
    if (quarter_seconds != prev_quarter_seconds) {
      every_quarter_second();
      prev_quarter_seconds = quarter_seconds;
    }
    process_btn();
    display_next_digit();
	}
}

// Interrupt handler (kept as simple/minimalistic as possible)
//  - When T16 'ticks' - Increment our quarter_seconds 'register'
void interrupt(void) __interrupt(0) __naked {
//	if (INTRQ & INTRQ_T16) {
//		quarter_seconds++;
//		INTRQ &= ~INTRQ_T16;
//	}
__asm
	t1sn.io	_REG(INTRQ), #INTRQ_T16_BIT
		goto  00001$
	push  af
	inc   _quarter_seconds
	set0.io	_REG(INTRQ), #INTRQ_T16_BIT
	pop   af
00001$:
	reti
__endasm;
}

unsigned char __sdcc_external_startup(void) {

#if defined(PFS154)
  PDK_SET_FUSE(FUSE_SECURITY_OFF|FUSE_IO_DRV_NORMAL|FUSE_BOOTUP_FAST);
#elif defined(PFS173)
  PDK_SET_FUSE(FUSE_SECURITY_OFF|FUSE_PB4_PB5_NORMAL|FUSE_BOOTUP_FAST);
#elif defined(PMS152)
  PDK_SET_FUSE(FUSE_SECURITY_OFF|FUSE_BOOTUP_FAST);
#elif defined(PMS154C)
  PDK_SET_FUSE(FUSE_SECURITY_OFF|FUSE_LVR_2V|FUSE_IO_DRV_NORMAL|FUSE_BOOTUP_FAST);
#else
  #error "Device not currently supported!"
#endif

  // Make sure we have a reasonable LVR value.
  // Red LEDs work at around 2V, so let's use that as our minimum.
#if defined(MISCLVR_2V)
  MISCLVR = (uint8_t) MISCLVR_2V;
#endif

  // Calibrate IHRC or ILRC for values that work better for timekeeping.
  // Nowhere near accurate enough for actual timekeeping, but good enough for debugging (i.e. testing without a crystal).
  // For real timekeeping, we use an external 32.768 kHz crystal as input to T16.
#if (F_CPU == 524288)
  PDK_SET_SYSCLOCK(SYSCLOCK_IHRC_500KHZ);
  EASY_PDK_CALIBRATE_IHRC(524288, TARGET_VDD_MV);
#elif (F_CPU == 65536)
  PDK_SET_SYSCLOCK(SYSCLOCK_ILRC);
  EASY_PDK_CALIBRATE_ILRC(65536, TARGET_VDD_MV);
#else
  #error "F_CPU not currently supported!"
#endif

  return 0;
}

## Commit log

2020-07-17 Add PCB files and renders
    [pcb-B_Cu.gbr, pcb-B_Mask.gbr, pcb-B_Paste.gbr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]
2020-07-19 Update schematic
    [pcb.sch]
2020-07-19 Add schematic to README.md
2020-07-20 Add README.md for the PCB
2020-07-24 Update Crystal
    [pcb.kicad_pcb, pcb.sch]
2020-08-01 Add values (680 ohm) for resistor arrays
    [pcb.kicad_pcb, pcb.sch]
2020-08-01 Add finished images, and Bill-of-materials
2020-08-01 Tweak bill of materials
2022-06-29 Add some power consumption numbers
2025-07-18 Fixes for newer version of SDCC
    [main.c]
2025-11-17 Add support for alternate digit pin layout
2025-11-17 Add support for another alternate digit pin layout that has separate blink segment pins.

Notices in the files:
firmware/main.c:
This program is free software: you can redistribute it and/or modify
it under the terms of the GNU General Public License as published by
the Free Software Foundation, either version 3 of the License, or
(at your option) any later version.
